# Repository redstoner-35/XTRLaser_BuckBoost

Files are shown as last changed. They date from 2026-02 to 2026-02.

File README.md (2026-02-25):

powered by 35's Embedded Systems Inc. A Next generation Driver Solution for Portable Mid Output Laser Pointer                                                                                                                     

### 概述

Xtern Ripper Laser BuckBoost Edition(简称XTRLaser-BuckBoost)是专用于驱动日亚、欧司朗等LD单管或者BANK拆出的LD单管 **（例如NUBM0F、NDG7H75、NUGM06、NDB7A75等）** 的高能效侧按电子开关控制的升降压恒流驱动器。该驱动器基于南芯SC872x系列升降压芯片，具备自适应功能。支持单锂和双锂输入并自动根据负载电压和电池电压采取升压或降压策略，实现无关于输入电压且全程恒流驱动3.0至5.5V额定工作电压的单管绿激光或蓝激光LD的功能。且该驱动器在3.3至8.4V电池电压输入下均能以满功率驱动单管大功率蓝或绿LD。该驱动的尺寸为22mm，高度3.5mm，可以完美兼容东东海D2GC或M0AC等22mm驱动位的侧按小直外壳。相比市面上基于LED手电筒驱动的魔改产物具有更高的稳定性和安全保护机制（软硬件协同实现的智能上电自我测试和负载识别序列，确保启动过程中0电流和电压过冲并保护二极管免受因驱动自身硬件或软件故障引起的损坏）避免烧毁昂贵的LD，以及更适配和更智能的温度保护和操作逻辑（一键点动烧灼模式，自动锁定等）。

### 性能数据

+ 支持的电池输入类型：1S至2S的三元锂电池组，2S电池组的放电能力需大于5A，1S的电池组放电能力需大于10A。 
+ 支持的LD类型：单个绿光(如NDG7H75)或者单个蓝光(如NDB7A75)激光二极管，不支持多管合一的LD Bank，如果您需要使用多管的LD Bank则请前往[XTRLaser MLD Boost Edition驱动](https://github.com/redstoner-35/XTRLaser)的项目Page查看相关的详情。**该驱动具备智能负载识别功能，故不支持普通LED和红光以及红外LD！强行使用虽然不会损坏驱动和LD但是会导致驱动进入保护模式，报错无法工作。**
+ 支持的LD电流：50mA至4.1A（适配常见大功率范围的单管蓝光和绿光LD）
+ 温度保护：45度多阶变值PI环+常亮预测算法实现的自适应外壳恒温（温控启动后驱动根据外壳散热能力和环境自动调整LD的亮度达到最高可实现的亮度，充分利用外壳的散热能力和热容）+55度极亮cutoff（强制退出极亮并返回到低亮）+65度强制关机三段式温度保护。**相比那些温度一到就给你拉闸不给开机的断崖式温度保护极大提高了用户的使用体验。都5202年了还没有一个能实现自适应恒温的激光驱动，属实是扯蛋。**
+ 电池保护：具有欠压自动降档和关机保护以及过电压保护
+ 输出保护：具备智能负载识别检测，驱动完成自我测试后，只有检测到合法的单管LD系统才会正常输出，否则会进入保护模式。

### 自动锁定功能说明

考虑到该类激光手电具有极高的输出功率，当用户长时间静置未用，并且在某天突然拿起时会因为忘记手电处于何种状态并误开启高功率模式造成严重的安全事故。**激光贴吧之前就有因为熊孩子误拿起长期静置且未处于锁定模式的大功率激光手电并且未做任何防护的情况下意外开启造成眼睛永久失明的案例！！** 因此该驱动固件具备自动锁定功能，当手电检测到用户长时间未使用并静置超过20分钟后，驱动将会自动进入锁定模式并且重置挡位记忆到最低挡位确保安全。进入锁定模式后即使重新安装电池也无法解锁，此时用户需要参考下方章节关于按键锁的内容，手动解锁手电后手电才会恢复正常使用状态。且解锁手电后，首次单击开机时手电会固定进入低挡位以确保安全使用，用户可以自行在循环模式下换挡，使用足够时间后关闭之后手电将会解除上电安全锁定，此时所有功能解锁。

### 基本功能操作逻辑

+ 调焦挡位：关机状态下单击+长按进入。该挡位下驱动会令LD在远低于其阈值电流的条件下运行输出无害的弱光用于进行光学系统测试或者对焦以及瞄准工作（也可以拿来逗猫玩 *笑）。该挡位下用户可以单击关闭，若长按则会进入到循环挡位模式的最低挡位。
+ 循环挡位模式：关机状态下单击进入。首次上电时驱动默认位于最低挡位，长按在`极低->低->中->中高->高`五个挡位内反复循环切换，达到高亮档之后自动长按则会循环到极低挡位。单击+长按则逆向按照`高->中高->中->低->极低`的顺序逐步降到最低并在极低亮挡位停止，单击关闭。
+ 无极调光模式：关机状态下长按进入。该挡位允许用户在0.1A至2A的范围内无极调整并选定一个指定的亮度挡位。进入该挡位后长按升高亮度，单击+长按减少亮度。若亮度达到最高或最低时驱动会令LD慢闪提示您亮度调整已经达到限制。若要回到关机状态，则单击开关一次。 **注：该挡位的亮度数据具有永久性记忆，设定好亮度后约3秒系统会永久保存至存储器内，即使断电也不会丢失。**
+ 极亮挡位：任意状态下双击进入，此时驱动由当前电流以软起动的方式缓慢升高到全功率输出。 **该挡位发热巨大且输出功率极高，为了避免引起火灾请务必小心使用！**
+ 特殊功能挡位：关机状态下三击进入，长按在`SOS->呼吸巡航灯->周期频闪信标灯`这三种特殊模式内按顺序循环切换。单击+长按则逆序循环切换。单击回到关机状态。对于这三个特殊功能挡位的具体功能则如下所示：
  - SOS：驱动令LD以0.8A电流点亮播报国际标准SOS求救信号（三短三长三短）并反复循环。每次播报结束后会停顿三秒再继续。
  - 呼吸巡航灯：驱动令LD工作在呼吸闪状态（亮度从低缓升最高后又缓降到最低，到最低后熄灭并停顿三秒后再次从最低亮度缓升并反复循环）
  - 周期频闪信标灯：进入后驱动首先以低亮度点亮LD约2秒提醒用户已经进入该模式。然后驱动每隔3秒令LD以额定功率短时间脉冲工作（约50mS）后立即关闭并进入休眠，3秒后再次启动输出脉冲并反复循环。 
+ 一键烧灼模式：关机状态下四击开关，此时驱动以远低于激光管阈值电流的最低功率点亮输出无害的弱光方便用户进行瞄准，按住开关则驱动立即以全功率工作进行烧灼，松开则回到低功率状态。若用户单击则回到关闭状态。该挡位具备超时和过温保护功能。若驱动电量不足或超过1分钟未操作，以及驱动发生过热事件后则会自动退出该操作模式并关机。
+ 按键锁：关机状态下五击开关，侧按指示灯红色闪三次进入锁定模式。进入锁定模式后，除了单击+长按临时开启几乎无害的低功率激光输出，松开手自动熄灭或开启20秒后自动熄灭以外（模拟人畜无害的低功率沙盘指星笔的行为，用于骗过安检），其余任何操作均会被驱动忽略并使用红色快闪5次提示用户。**为了保证安全，进入锁定模式后即使重新安装电池，激光手电也会始终保持在锁定状态。** 在锁定状态下再次五击，侧按指示灯绿色闪烁三次，并且LD以低功率点亮0.5秒表示成功解锁，此时驱动回到正常操作模式可以正常操作。 **需要注意的是，系统在每次退出锁定模式后会进入低功率的保护模式，此时驱动除了开启0.5W的最低档位和调焦挡位以外，其他的所有功能均会被禁用以避免激光手电用于自卫的武器化用途。驱动只有在低功率运行足够时间并手动单击关闭输出后，方可解锁所有功能并恢复正常使用。** 

### 特殊功能操作逻辑

+ 应急求救挡位：关机状态下五击+长按进入，驱动令LD以0.6A电流点亮播报国际标准SOS求救信号（三短三长三短）并反复循环。每次播报结束后会停顿三秒再继续。该挡位只要电池在静置状态下电压高于2.5V就会持续运行并一直发送信号，可以让用户在紧急情况下以报废电池的小小代价持续的发射求救信号并获得一线生机。 **对于非紧急状态不建议使用该挡位，以免电池过度放电并永久损毁。**
+ 重置无极调光亮度：在关机状态下四击+长按，驱动将会重置无极调光亮度至最低值并进入无极调光模式，其余操作请参考基本功能章节内的无极调光操作指引。
+ 固件编译时间戳查询：关机状态下8击进入。进入后驱动将会令LD点亮1秒，提示即将开始播报。然后驱动将会按顺序播报固件编译的年份、月份，日期以及编译时的时间（精确到分钟）。首先驱动会播报固件编译的具体日期，播报会分为三组数字，每组数字之间停顿2.5秒，同一组数字之间会有1.5秒的间隔方便用户区分。在播报完第一到第三组数字所表示的驱动编译固件编译的年份、月份，日期之后，驱动将会停顿4.5秒然后开始播报固件编译的具体时间（精确到分钟）。具体编译时间的播报会分为两组数字，每组数字之间停顿2.5秒，同一组数字之间会有1.5秒的间隔方便用户区分。**需要注意的是，播报启动后就无法中断，在版本信息播报过程中，驱动将不响应任何操作，直到播报结束。** 详细的播报规则如下：
 
  - 第一组数字：指示固件编译的年份。其中LD慢速闪烁N次表示非零的数字，如果快速闪烁一次，则表示该数据位为0。两位数字之间系统会停顿1.5秒。例如`慢闪2次-停顿1.5秒-慢闪5次`表示固件编译的年份为**25（2025年）**。
  - 第二组数字：指示固件编译的月份。其中LD慢速闪烁N次表示非零的数字，如果快速闪烁一次，则表示该数据位为0。两位数字之间系统会停顿1.5秒。例如`快闪1次-停顿1.5秒-慢闪9次`表示固件编译的月份为**09（9月）**。
  - 第三组数字：指示固件编译的具体日期（精确到天）。其中LD慢速闪烁N次表示非零的数字，如果快速闪烁一次，则表示该数据位为0。两位数字之间系统会停顿1.5秒。例如`慢闪3次-停顿1.5秒-快闪1次`表示固件编译的具体日期为**30日**。
  - 第四组数字：以24小时制度指示固件编译时间的小时部分。其中LD慢速闪烁N次表示非零的数字，如果快速闪烁一次，则表示该数据位为0。两位数字之间系统会停顿1.5秒。例如`慢闪1次-停顿1.5秒-慢闪3次`表示固件编译的时间（小时）为**13时（下午1点）**。
  - 第五组数字：指示固件编译时间的分钟部分。其中LD慢速闪烁N次表示非零的数字，如果快速闪烁一次，则表示该数据位为0。两位数字之间系统会停顿1.5秒。例如`慢闪4次-停顿1.5秒-慢闪6次`表示固件编译的时间（分钟）为**46分**。

+ 设置按键有源夜光功能：关机状态下七击按键，驱动令侧按指示灯以绿色快闪一次表示功能开启。若以红色快闪一次则表示功能关闭。该功能开启后，驱动将会在闲置未用且电池电压充足的情况下令按键发出微弱绿光指示激光手电的开关位置，方便用户在全黑环境中进行操作。
+ 温度查询模式：驱动任意状态下三击+长按进入。当进入温度查询模式后激光手电的颈部开关指示灯首先将会以红黄绿依次点亮的方式（**若激光手电当前处于极寒环境使得驱动本身的温度低于0摄氏度时，先导提示将变为绿黄红的顺序**）作为先导提示，提示用户手电即将开始显示当前的内部温度（由驱动的内置的NTC热敏电阻测得）。延迟1秒后驱动将通过红色和黄色的指定次数的慢速闪烁（如果快速闪烁一次，则表示该数据位为0）提示用户当前的驱动温度。在播报完当前驱动的温度数值后，驱动将会在延迟2秒后通过后续的长亮(或者慢闪)提示用户当前驱动的具体温度值所对应的手电整体散热情况。对于温度显示的计算方式请参考如下内容：

  - 播报完毕后绿色常亮：当前手电散热良好，内部温度正常
  - 播报完毕后黄色常亮：当前手电内部温度较高，请注意防止烫手
  - 播报完毕后红色常亮：当前手电内部温度温度极高，请及时为手电散热并且避免被烫伤   
  - 驱动温度(℃)=红色闪烁次数x10+黄色闪烁次数，例如`红色慢闪4次-黄色快闪1次`表示当前驱动所测到的内部温度为40℃

+ 电池电压和电量查询功能：驱动任意状态下通过双击+长按进入。当进入电量查询模式后手电的颈部开关指示灯首先将会以红黄绿依次点亮的方式（**若电池电压低于10.00V，则系统将会切换到高精度显示模式以0.01V精度显示电量。此时先导提示将变为绿黄红的顺序**）作为先导提示，提示用户驱动即将开始显示电池电压和电量。延迟1秒后驱动将通过红色，黄色和绿色的指定次数的慢速闪烁（如果快速闪烁一次，则表示该数据位为0）提示用户当前的电池电压，播报完电池当前电压后，驱动将会在延迟2秒后通过后续的长亮(或者慢闪)提示用户当前电池电压对应的总体电量水平（指示方式参考下文中驱动位于正常工作时的指示），对于电池具体电压播报的计算方式请参考如下内容：
  
  -  99.9V显示模式：红色闪烁次数x10+黄色闪烁次数+绿色闪烁次数x0.1=当前电池电压(V)，例如`红色慢闪1次-黄色快闪1次-绿色慢闪4次`表示电池电压为10x1+0+4x0.1=10.4V。
  -  9.99V高精度显示模式：红色闪烁次数+黄色闪烁次数x0.1+绿色闪烁次数x0.01=当前电池电压(V)，例如`红色慢闪8次-黄色慢闪1次-绿色慢闪3次`表示电池电压为8+1*0.1+3x0.01=8.13V。

+ 恢复出厂设置：在驱动处于完全断电状态下（用户可以通过卸下电池并反复多次按下手电的侧按按钮直到手电没有任何反应）持续按住按钮并扭上电池包令驱动通电。此时驱动的侧部按键指示灯将会以黄色的持续高频率快闪提示用户已恢复出厂设置。用户松开按键后，驱动将会在2秒后自动重启并进入正常工作状态。

### 正常工作时的电量指示

对于电压指示，驱动在正常挡位的工作状态会通过指示灯点亮的方式提示用户当前系统的电池电量（如果驱动当前处于无保护的SOS应急求生挡位，则驱动的电量指示灯会改为每5秒短暂点亮一次以节约电力消耗）。与此同时，在驱动首次装入电池时，驱动还会通过一次持续2秒的点亮提示电池电量（指示方式和工作状态时相同）。对于驱动当前的电量状态和对应的指示灯状态请参考如下内容：

  - 绿色常亮：电池电量充足
  - 黄色常亮：电池电量较为充足
  - 红色常亮：电池电量不足，请尽快为电池充电
  - 红色慢闪：电池电量严重不足，请立即为电池充电（此时驱动的功能将会被限制）

与此同时，在驱动正常工作时，驱动还会再某些特定事件发生时通过一定时间内的短时间熄灭次数的循环指示驱动发生的事件，详细的事件列表如下：

  + 每2秒瞬时熄灭1次：驱动检测到外壳温度过高，驱动已启用温控限制驱动输出功率避免LD过热光衰

### 电池参数配置

该激光驱动同时支持单锂和双锂电的操作，驱动可以自动检测双锂电的插入并切换为双锂电池模式，该驱动在单锂和双锂模式下均开放所有功能，使用体验一致。对于电池配置模式用户也可以随时进行手动调整。对于如何确认系统当前的电池配置以及调整配置等，请参考如下内容：

+ 识别系统当前的电池配置：在每次装入电池时，电量指示灯会进行自检并显示当前电池电量。如果当前系统开启了双锂电模式，则系统在装入电池后首先会以黄色快闪2次，延迟0.5秒后再显示电池电量（假设电量充足，则指示灯将绿色常亮3秒）。若当前为单锂模式，则驱动将会直接提示电池电量。
+ 双锂电自动识别功能：当系统处于单锂电模式时，如果用户装入两节电池，则系统会检测到并自动切换至双锂模式。此时系统会通过令侧按指示灯黄色快速频闪3次作为检测到双锂的提示，延迟1秒后系统将会自动重启并切换为双锂模式。
+ 切换单锂/双锂模式：用户可以通过在关机状态下六击+长按侧按切换单锂和双锂模式。当切换为单锂模式时，激光手电的侧按将会通过绿色快速频闪3次提示已经成功切换。如果是切换为双锂模式，则激光手电的侧按将会通过黄色快速频闪3次提示成功切换。切换完毕后，系统将会在延迟1秒后自动重启以应用电池节数的更改。**需要注意的是，如果系统当前安装了2节电池，为了保护电池避免过度放电，此时系统将会禁止用户切换为单节锂电池模式。如果您需要从双锂模式切换至单锂模式，请将电池取出并仅安装一节电池，再进行切换操作。**

### 编译固件时MCU的CONFIG配置

由于中微单片机内部有一组硬编码于Flash指定区域，用于设置单片机的硬件首选项（例如看门狗，调试模式，低电压保护点等）的配置Word。为了确保编译出来的固件可以在硬件内正常运行，您需要在工程配置(Options for Target 'XTRLaser'->Debug选项卡->右上角的Settings按钮)的Config设置菜单，按照下表正确填写MCU的配置。错误的CONFIG设置会引起固件工作异常！

+ Power                      :  Inter 3.3V            
+ WDT                        :  SOFTWARECONTROL     
+ PROTECT                    :  ENABLE              
+ FLASH_DATA_PROTECT         :  ENABLE              
+ LVR                        :  1.8V                
+ DEBUG                      :  Disable             
+ OSC                        :  HSI                 
+ OSC_PRESCALE               :  Fosc/1              
+ HSI_FS                     :  Fhsi/1              
+ EXT_RESET                  :  DISABLE             
+ EXT_RESETSEL               :  P00                 
+ WAKEUP_WAITTIME            :  500us               
+ CPU_WAITCLOCK              :  2T                  
+ WRITE_PROTECT[0-2K]        :  DISABLE             
+ WRITE_PROTECT[2-4K]        :  DISABLE             
+ WRITE_PROTECT[4-6K]        :  DISABLE             
+ WRITE_PROTECT[6-8K]        :  DISABLE             
+ WRITE_PROTECT[8-10K]       :  DISABLE             
+ WRITE_PROTECT[10-12K]      :  DISABLE             
+ WRITE_PROTECT[12-14K]      :  DISABLE             
+ WRITE_PROTECT[14-16K]      :  DISABLE             
+ BOOT                       :  BOOT_DIS 

### 运行时错误监测和错误ID汇报

该驱动具备错误监视和自动负载识别监控系统，在每次上电启动和运行期间，驱动将会执行自我测试和负载类型识别序列。在这期间若驱动检测到无法解决的致命问题则会进入保护模式避免驱动自身和昂贵的激光二极管损毁，并通过颈部侧按键的指示灯提示用户发生的错误类型。每个指示循环首先以红黄绿的颜色切换闪烁开始，然后通过紧跟着的红色慢闪次数指示错误ID号，慢闪结束后会停顿一会并重新开始循环，对于ID号所对应的错误描述请参考如下内容：

+ 闪烁1次(Fault_NTCFailed) 驱动在运行期间检测到测量驱动温度的热敏电阻出现异常，检查热敏电阻和测温部分的上拉电阻是否损坏。
+ 闪烁2次(Fault_OverHeat) 驱动检测到外壳温度过高，请等待手电冷却。冷却后故障会自动解除并返回正常操作模式。
+ 闪烁3次(Fault_InputOVP) 驱动检测到输入电压过高，请检测驱动的电池配置是否和使用的电池配套，驱动的电池电压检测机制是否正常。
+ 闪烁4次(Fault_DCDC_I2C_CommFault) 驱动在上电自我测试时无法和DCDC转换芯片通信以获取数据或下发配置，检查DCDC芯片是否损坏以及固件配置是否正确
+ 闪烁5次(Fault_DCDCVOUTTestError) 驱动在进行上电的DCDC自我测试时检测到DCDC芯片输出电压不受控，为了避免烧毁LD已进入保护模式。检查DCDC的外围电路是否故障。
+ 闪烁6次(Fault_InvalidLoad) 驱动在进行负载识别时检测到非法的负载类型。为了避免损坏驱动自身和负载，驱动已进入保护模式。**该驱动不支持除了单管绿光和蓝光LD以外的任何负载！包括可见光LED、VCSEL、红光和红外LD以及UV LED**
+ 闪烁7次(Fault_DCDCShort)  驱动在启动和运行时检测到输出短路，检查负载是否击穿损坏以及驱动正极输出线是否对地短路。
+ 闪烁8次(Fault_DCDCOpen) 驱动在运行时检测到输出空载，请检查激光二极管是否出现开路损坏并确认驱动输出到负载之间正确连接。
+ 闪烁9次(Fault_DCDC_TSD) 驱动运行过程中检测到DCDC转换芯片出现过热并自动关闭输出，说明驱动的DCDC芯片发热过大且散热不足，需要改善驱动的散热和导热措施。
+ 闪烁10次(Fault_MCUVDD_Error) 驱动运行过程中检测到为主控MCU供电的LDO发生故障导致MCU电源不稳定。检查LDO是否损坏导致MCU供电异常。
+ 闪烁11次(Fault_RampConfigError) 驱动固件编译时存在异常导致无极调光功能数据丢失，检查固件编译时是否出错。

部分非严重的错误您可以尝试长按清除错误并返回到正常模式，此时驱动可以继续运行。对于严重的异常则无法复位，此时需要断电并检查引起驱动报警进入保护模式的原因并给予修复，否则错误提示会再次出现。

----------------------------------------------------------------------------------------------------------------------------------
© redstoner_35 @ 35's Embedded Systems Inc.  2026

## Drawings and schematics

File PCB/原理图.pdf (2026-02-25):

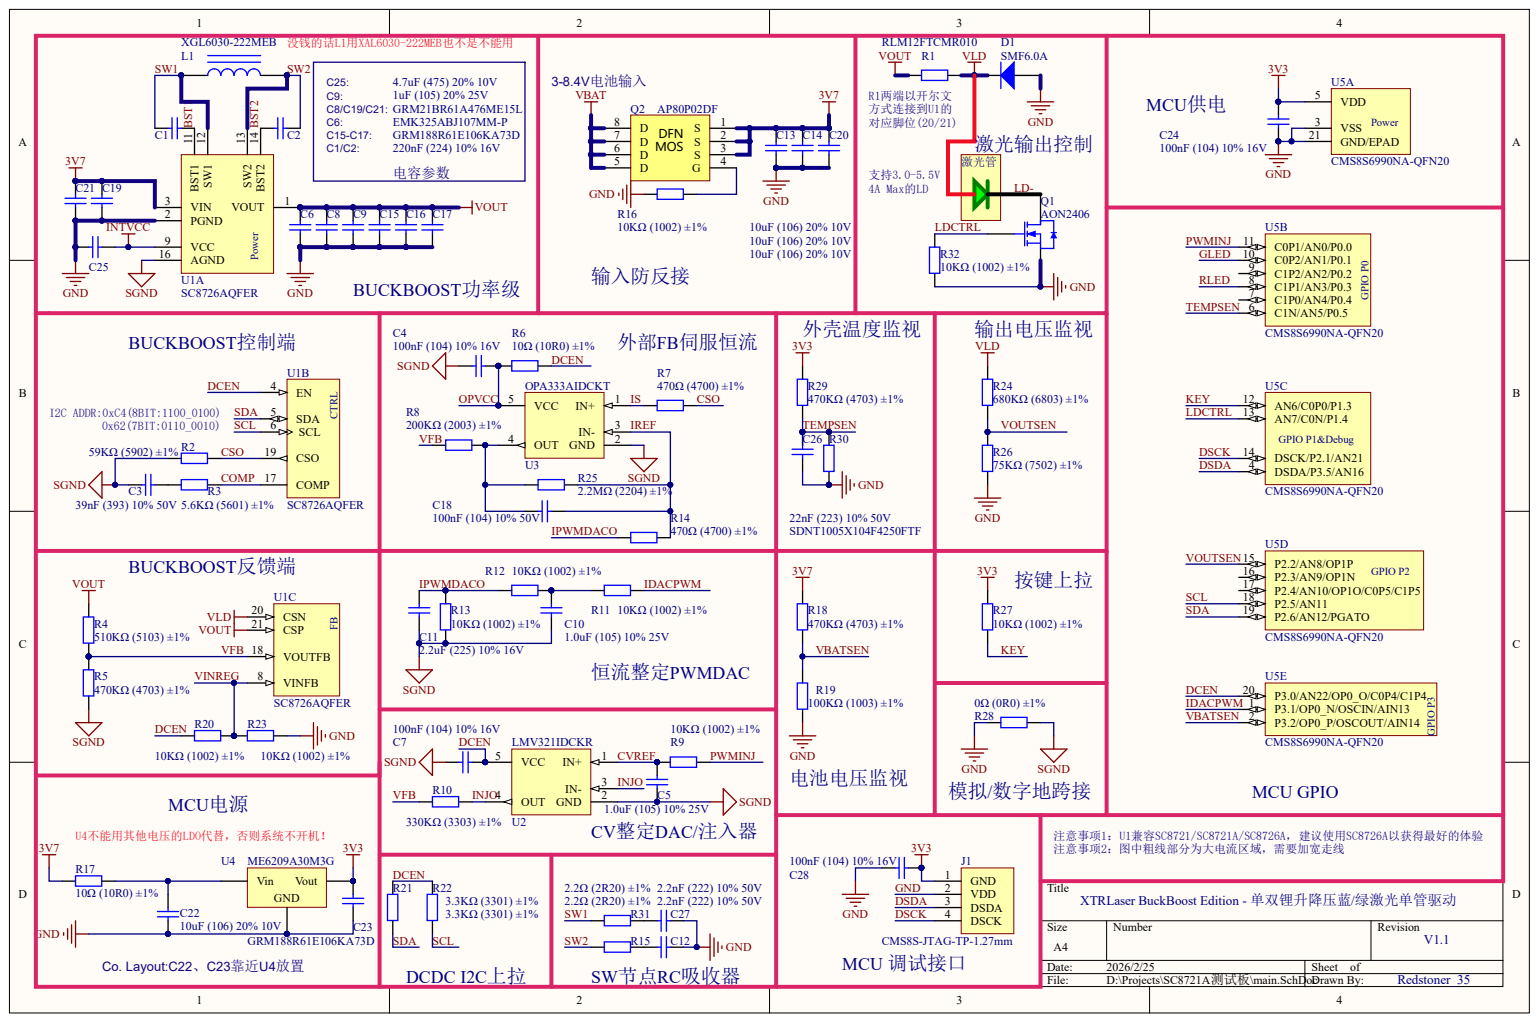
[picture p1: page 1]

INTVCC | VCC 9

AGND 16

Title
XTRLaser BuckBoost Edition - 单双锂升降压蓝/绿激光单管驱动

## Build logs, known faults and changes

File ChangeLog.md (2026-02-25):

# 更新日志

## [1.0.0.1] - FEB-25-2025 17:48

### 驱动固件勘误

+ 修复错误监视系统的错误播报功能的显示错误（输出短路条件下错误报告DCDC Open）
+ 修改DCDC开路判断逻辑，DCDC正常输出下才进行报告

### 驱动固件更新

本次没有驱动固件更新内容

### 硬件勘误

本次没有硬件勘误内容

### 其余更新

+ 将系统的预编译固件移动到[Firmware](./Firmware/)文件夹内。
+ 将原本的固件源代码的文件夹名称修改为[FirmwareCode](/FirmwareCode/)
+ 新增针对日亚NDG7H75、NDB7A75激光管的预编译固件文件

## [1.0.0.0] - FEB-25-2025 13:06

### 驱动固件勘误

本次没有驱动固件勘误内容

### 驱动固件更新

+ 初始分支首次提交固件源代码

### 硬件勘误

本次没有硬件勘误内容

### 其余更新

+ 初始分支首次提交初始版PCB文件（包括驱动主PCB和侧按PCB）

----------------------------------------------------------------------------------------------------------------------------------
© redstoner_35 @ 35's Embedded Systems Inc.  2026

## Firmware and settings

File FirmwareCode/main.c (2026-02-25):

/****************************************************************************/
/** \file main.c
/** \Author redstoner_35
/** \Project Xtern Ripper Laser Edition 
/** \Description 这个文件负责系统的主函数处理

**	History: Initial Release
**	
*****************************************************************************/
/****************************************************************************/
/*	include files
*****************************************************************************/
#include "cms8s6990.h"
#include "GPIO.h"
#include "delay.h"
#include "SideKey.h"
#include "LEDMgmt.h"
#include "ADCCfg.h"
#include "PWMCfg.h"
#include "LVDCtrl.h"
#include "SysReset.h"
#include "LowVoltProt.h"
#include "TempControl.h"
#include "BattDisplay.h"
#include "OutputChannel.h"
#include "SelfTest.h"
#include "SOS.h"
#include "BreathMode.h"
#include "Beacon.h"

/****************************************************************************/
/*	Local variable  definitions('static')
****************************************************************************/
bit TaskSel=0;  //选择处理的系统任务

/****************************************************************************/
/*	External Function prototypes definition
****************************************************************************/
void SleepMgmt(void);

//主函数
void main(void)
	{
	//时钟和RSTCU初始化	
	ClearSoftwareResetFlag();
	LVD_Disable(); 				 //启动系统前每次确保WUT处于一个已知状态
  StartSystemTimeBase(); //启动系统定时器提供系统定时和延时函数
	//初始化外设
	ADC_Init(); //初始化ADC
	PWM_Init(); //启动PWM定时器
	LED_Init(); //初始化侧按LED
  SideKeyInit(); //侧按初始化	
	OutputChannel_Init(); //输出初始化	
	ModeFSMInit(); //初始化模式状态机
  DisplayVBattAtStart(1); //显示电池状况
	EnableADCAsync(); //启动ADC的异步模式提高处理速度
	//主循环	
  while(1)
		{
	  //实时处理
		SystemTelemHandler();
		BatteryTelemHandler(); //获取ADC和电池信息	
		SideKey_LogicHandler(); //处理侧按事务
		ThermalMgmtProcess(); //温度管理
		ModeSwitchFSM(); //挡位状态机
		OutputChannel_Calc();  //输出通道处理
		PWM_OutputCtrlHandler(); //处理PWM输出事务	
		//8Hz交错定时处理
		if(!SysHFBitFlag)continue; //时间没到，跳过处理
			
		//Task0，处理计算量比较大的任务
    if(!TaskSel)
			{
			LEDControlHandler();//侧按指示LED控制函数	
			BattAlertTIMHandler(); //电池警报定时处理
			OutputFaultDetect(); //输出故障检测
			ThermalPILoopCalc(); 				//积分器计算	
			SleepMgmt(); //睡眠处理
			BreathFSM_TIMHandler(); //呼吸模式状态机计时处理
			
			//处理结束，对任务选择进行翻转处理下一组
			TaskSel=1;
		  }			
		//Task1，处理计算量比较小的计时任务
		else
			{	
			SideKey_TIM_Callback();//侧按按键的监测定时器处理		
			BattDisplayTIM(); //电池电量显示TIM
			DisplayErrorTIMHandler(); //故障代码显示
			ModeFSMTIMHandler(); //模式状态机处理
			HoldSwitchGearCmdHandler(); //长按换挡处理
			SOSTIMHandler(); //SOS定时器
			BeaconFSM_TIMHandler(); //信标计时器
			OutputChannelFSM_TIMHandler(); //输出通道计时	
				
			//处理结束，对任务选择进行翻转处理下一组
			TaskSel=0;
			}
		//处理完毕，令flag清零
		SysHFBitFlag=0;	
		}
	}

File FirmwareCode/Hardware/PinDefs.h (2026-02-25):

/************************************************************************************/
/** \file PinDefs.h
/** \Author redstoner_35
/** \Project Xtern Ripper Laser Edition 
/** \Description 这个文件为底层的硬件定义文件，定义了整个工程内所有外设对应的硬件PIN和模
拟输入ADC通道的映射关系。

**	History: Initial Release
**	
/************************************************************************************/
#ifndef PINDEFS
#define PINDEFS
/************************************************************************************/
/* Include files */
/************************************************************************************/
#include "GPIOCfg.h"

/************************************************************************************
以下是系统的常规GPIO以及部分特殊的数字功能引脚，用于控制外部外设切换功能
************************************************************************************/
#define DCDCENIOP GPIO_PORT_3
#define DCDCENIOG 3
#define DCDCENIOx GPIO_PIN_0 //LD的DCDC电源使能引脚(P3.0)

#define LDMOSENIOP GPIO_PORT_1
#define LDMOSENIOG 1
#define LDMOSENIOx GPIO_PIN_4 //LD路径MOS的使能(P1.4)

#define DCDCSCLGPIOP GPIO_PORT_2
#define DCDCSCLGPIOG 2
#define DCDCSCLGPIOx GPIO_PIN_5		//DCDCSCL引脚(P2.5)

#define DCDCSDAGPIOP GPIO_PORT_2
#define DCDCSDAGPIOG 2
#define DCDCSDAGPIOx GPIO_PIN_6		//DCDCSDA引脚(P2.6)

/************************************************************************************
以下是系统的PWM输出引脚，用于对外输出PWM控制DCDC输出电压和电流等等
************************************************************************************/

#define PWMDACIOP GPIO_PORT_3
#define PWMDACIOG 3
#define PWMDACIOx GPIO_PIN_1		//恒流(CC)整定PWMDAC输出(P3.1)

#define PreChargeDACIOP GPIO_PORT_0
#define PreChargeDACIOG 0
#define PreChargeDACIOx GPIO_PIN_0		//恒压预充(CV)整定PWMDAC输出(P0.0)

/************************************************************************************
以下是系统的模拟输入引脚，例如电池电压测量等
************************************************************************************/
#define NTCInputIOG 0
#define NTCInputIOx GPIO_PIN_5 
#define NTCInputAIN 5						//NTC输入(P0.5,AN5)

#define VOUTFBIOG 2
#define VOUTFBIOx GPIO_PIN_2
#define VOUTFBAIN 8						//输出电压反馈引脚(P2.2,AN8)

#define VBATInputIOG 3
#define VBATInputIOx GPIO_PIN_2
#define VBATInputAIN 14					//电池电压检测引脚(P3.2,AN14)

/************************************************************************************
以下是系统的按键模块的GPIO引脚，负责驱动负责按键小板部分(包括指示灯和按键本身) 
************************************************************************************/
#define SideKeyGPIOP GPIO_PORT_1
#define SideKeyGPIOG 1
#define SideKeyGPIOx GPIO_PIN_3 	//侧按按键(P1.3)


#define RedLEDIOP GPIO_PORT_0
#define RedLEDIOG 0
#define RedLEDIOx GPIO_PIN_3		//红色指示灯(P0.3)	


#define GreenLEDIOP GPIO_PORT_0
#define GreenLEDIOG 0
#define GreenLEDIOx GPIO_PIN_1		//绿色指示灯(P0.1)

#endif /* PINDEFS */

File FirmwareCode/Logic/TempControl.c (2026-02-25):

/****************************************************************************/
/** \file TempControl.c
/** \Author redstoner_35
/** \Project Xtern Ripper Laser Edition 
/** \Description 这个文件是顶层应用层文件，负责根据系统温度动态调整输出功率在最大
限度利用外壳散热能力的同时避免系统过热。

**	History: Initial Release
**	
*****************************************************************************/
/****************************************************************************/
/*	include files
*****************************************************************************/
#include "ADCCfg.h"
#include "LEDMgmt.h"
#include "delay.h"
#include "ModeControl.h"
#include "TempControl.h"
#include "BattDisplay.h"
#include "OutputChannel.h"
#include "PWMCfg.h"
#include "LowVoltProt.h"
#include "SelfTest.h"
#include "FastOp.h"

/****************************************************************************/
/*	Local pre-processor symbols/macros('#define')
****************************************************************************/

//PI环参数和最小电流限制
#define ILEDRecoveryTime 120 //使用积分器缓慢升档的判断时长，如果积分器持续累加到这个时长，则执行一次调节(单位秒)
#define SlowStepDownTime 60 //使用积分器缓慢降档的判断时长，如果积分器持续累加到这个时长，则执行一次调节(单位秒)
#define IntegralCurrentTrimValue 2500 //积分器针对输出的电流修调的最大值(mA)
#define IntegralFactor 12 //积分系数(每单位=1/8秒，越大时间常数越高，6=每分钟进行40mA的调整)
#define MinumumILED 390 //降档系统所能达到的最低电流(mA)

//常亮电流配置
#define ILEDConstant 750 //降档系统内温控的常亮电流设置(mA)
#define ILEDConstantFoldback 500 //在接近温度极限时的降档系统内的常亮电流设置(mA)

//温度配置
#define ForceOffTemp 65 //过热关机温度
#define ForceDisableTurboTemp 50 //超过此温度无法进入极亮
#define ConstantTemperature 45 //非极亮挡位温控启动后维持的温度
#define ReleaseTemperature 40 //温控释放的温度
#define LeaveTurboTemperature ForceOffTemp-10   //退出极亮温度为关机保护温度-10

/*   积分器满量程自动定义，切勿修改！    */
#define IntegrateFullScale IntegralCurrentTrimValue*IntegralFactor

#if (IntegrateFullScale > 32000)
	//算出的积分器量程大于32000，非法值
	#error "Error 001:Invalid Integral Configuration,Trim Value or time-factor out of range!"
#endif

#if (IntegrateFullScale <= 0)
	//算出的积分器量程为0值，报错
	#error "Error 002:Invalid Integral Configuration,Trim Value or time-factor must not be zero or less than zero!"
#endif
/****************************************************************************/
/*	Global variable definitions(declared in header file with 'extern')
****************************************************************************/

bit IsPauseStepDownCalc; //是否暂停温控的计算流程（该bit=1不会强制复位整个温控系统，但是会暂停计算）
bit IsDisableTurbo;  //禁止再度进入到极亮档
bit IsForceLeaveTurbo; //是否强制离开极亮档

/****************************************************************************/
/*	Local type definitions('typedef')
****************************************************************************/

/****************************************************************************/
/*	Local variable  definitions('static')
****************************************************************************/
//内部变量
static xdata int TempIntegral;
static xdata int TempProtBuf;
static xdata unsigned char StepUpLockTIM; //计时器

//内部状态位
static bit IsNearThermalFoldBack; //标记位，是否接近于退出极亮温度
static bit IsThermalStepDown; //标记位，是否降档
static bit IsTempLIMActive;  //温控是否已经启动
static bit IsSystemShutDown; //是否触发温控强制关机

/****************************************************************************/
/*	Function implementation - local('static')
****************************************************************************/

static void ThermalIntegralHandler(bool IsStepDown,bool IsEnableFastAdj)	//温控系统中积分追踪温度变化实现恒亮的处理
	{
	int Buf;
	//条件定义，如果积分值小于上限且系统需要快速调整，则令积分器以和温度挂钩的可变速率工作
	#define IsEnableQuickItg (abs(TempIntegral)<(IntegrateFullScale-Buf)&&IsEnableFastAdj)
	//计算温度差和积分数值
	if(IsStepDown)Buf=Data.Systemp-(LeaveTurboTemperature-8);
	else Buf=(ReleaseTemperature+5)-Data.Systemp; //降档模式下系统温度误差值为强制极亮的温度-8，升档模式为恢复温度+5
	if(IsNegative16(Buf))Buf=0; //温度差不能为负数
	//进行积分器本次调整值的计算
	if(IsEnableQuickItg)Buf<<=1;      //快速调整开启,令调整值=温差*2
	else Buf=0;
	Buf++;  													//这里需要保证Buf始终为1(快速调整被禁用后调整值将会变为0)确保积分器正常响应
  //应用积分数值到积分缓存
	TempIntegral+=(IsStepDown?Buf:-Buf);
	#undef IsEnableQuickItg            //这个宏定义只是该函数的局部定义，需要在函数末尾禁用掉避免后续意外使用到导致问题
	}
	
//系统低于常亮电流，进入积分器缓慢追踪系统温度的时候把超过积分器量程的部分push到比例器去，腾出积分器并继续追踪的模块
static void ThermalIntegralCommitToProtHandler(void)	
	{
	//当前积分器累计的参数小于复位时间，退出
	if(abs(TempIntegral)<(ILEDRecoveryTime*8))return;
	//将积分器内累积的变化成比例应用到比例项并清零积分器
	TempProtBuf+=TempIntegral/IntegralFactor;
	TempIntegral=0;						
	}

//负责温度使能控制的施密特触发器
static bit TempSchmittTrigger(bit ValueIN,char HighThreshold,char LowThreshold)	
	{
	if(Data.Systemp>HighThreshold)return 1;
	if(Data.Systemp<LowThreshold)return 0;
	//数值保持，没有改变
	return ValueIN;
	}

/****************************************************************************/
/*	Function implementation - global ('extern')
****************************************************************************/

bit QueryIsThermalStepDown(void)	//获取系统是否触发降档
	{
	//当前处于电量显示状态不允许打断降档提示
	if(VshowFSMState!=BattVdis_Waiting)return 0; 
	//返回提示标志位
	return IsThermalStepDown;
	}

//换挡的时候根据当前恒温的电流重新PI值
void RecalcPILoop(int LastCurrent)	
	{
	int buf,ModeCur;
	//目标挡位不需要计算,复位比例缓存
	if(!CurrentMode->IsNeedStepDown)TempProtBuf=0;
	//需要复位，执行对应处理
	else
		{	
		//获取当前挡位电流
		ModeCur=QueryCurrentGearILED();
		//计算P值缓存
		buf=TempProtBuf+(TempIntegral/IntegralFactor); //计算电流扣减值
		if(IsNegative16(buf))buf=0; //电流扣减值不能小于0
		buf=LastCurrent-buf; //旧挡位电流减去扣减值得到实际电流(mA)
		TempProtBuf=ModeCur-LastCurrent; //P值缓存等于新挡位的电流-旧挡位实际电流(mA)
		if(IsNegative16(TempProtBuf))TempProtBuf=0; //不允许比例缓存小于0
		}
	//清除积分器缓存
	TempIntegral=0;
	}
	
//输出当前温控的限流值
int ThermalILIMCalc(void)
	{
	int result;
	//判断温控是否需要进行计算
	if(!IsTempLIMActive)
		{
		result=Current; 				//温控被关闭，电流限制进来多少返回去多少
		IsThermalStepDown=0;  	//指示温控已被关闭
		}
	//开始温控计算
	else
		{
		result=TempProtBuf+(TempIntegral/IntegralFactor); //根据缓存计算结果
		if(IsNegative16(result))result=0; //不允许负值出现
		result=Current-result; //计算限流值结果
		if(result<MinumumILED) //已经调到底了，禁止PID继续累加
			{
		  TempProtBuf=Current-MinumumILED; //将比例输出结果限幅为最小电流
		  TempIntegral=0;
		  result=MinumumILED; //电流限制不允许小于最低电流
			}
    //判断温控是否已经触发			
		if(result<(Current-150))IsThermalStepDown=1;	//温控已经让输出电流下调200mA，提示温控触发
		}
	//返回结果	                               
	return result; 
	}
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
